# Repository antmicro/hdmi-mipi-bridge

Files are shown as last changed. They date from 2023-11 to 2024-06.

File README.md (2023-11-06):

# HDMI to MIPI CSI-2 Bridge

Copyright (c) 2017-2023 [Antmicro](https://www.antmicro.com)

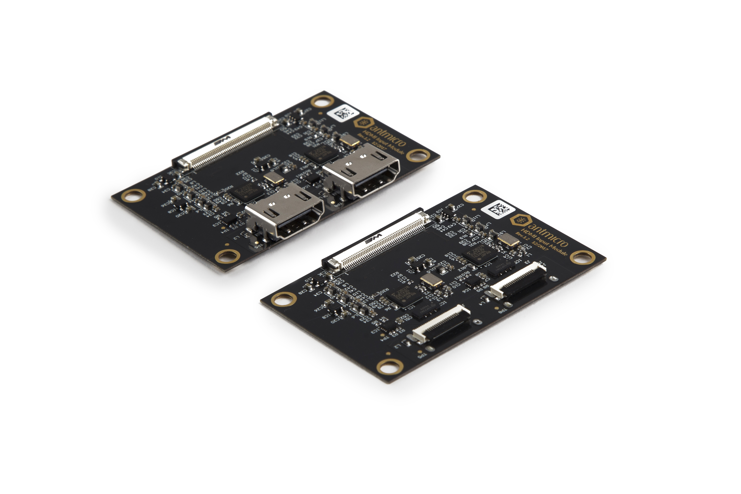
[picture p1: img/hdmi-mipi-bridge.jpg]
HDMI-MIPI Bridge


## Overview
This repository contains the open hardware design files for Antmicro's HDMI-MIPI Bridge, which is a video accessory converting HDMI video stream into MIPI CSI-2 counterpart.
The conversion is performed using Toshiba [TC358743XBG](https://toshiba.semicon-storage.com/ap-en/semiconductor/product/interface-bridge-ics-for-mobile-peripheral-devices/hdmir-interface-bridge-ics/detail.TC358743XBG.html) HDMI interface bridge.
The board includes two independent conversion channels supporting up to two HDMI streams.

## Repository structure:

The main repository directory contains KiCad PCB project files, a [LICENSE](LICENSE), and a README.
The remaining files are stored in the following directories:

* `lib` - contains component libraries
* `doc` - contains generated schematics and other documentation
* `img` - contains graphics for this README

## Key features

* Two independent HDMI-MIPI CSI-2 conversion channels
* Converted MIPI CSI-2 data is exposed on two 4-lane interfaces
* Two assembly variants for regular HDMI and FFC connectors

## Supported platforms

The board exposes MIPI CSI-2 data on a unified 50-pin FFC connector which is electrically compatible with a variety of processing platforms designed by Antmicro.
Those platforms include: 

* [Jetson Nano / Xavier NX Baseboard](https://github.com/antmicro/jetson-nano-baseboard)
* [Jetson Orin NX Baseboard](https://github.com/antmicro/jetson-orin-baseboard)
* [Google Coral Baseboard](https://github.com/antmicro/google-coral-baseboard)
* [Apalis Smart Vision Baseboard](https://github.com/antmicro/apalis-smart-vision-baseboard)
* [TX2 Deep Learning Platform](https://github.com/antmicro/jetson-tx2-deep-learning-platform)

Please note that some additional work might be required to integrate this board with a particular host platform.
Antmicro’s services involve BSP development so you can hire us to make the necessary modifications.

## License

This project is licensed under the [Apache-2.0](LICENSE) license.

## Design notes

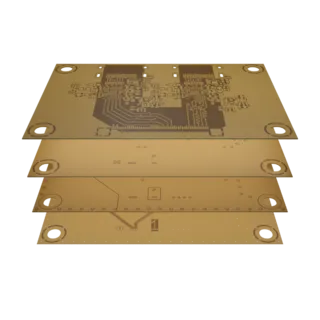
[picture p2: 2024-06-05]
assets/previews/layer1_thumbnail.webp

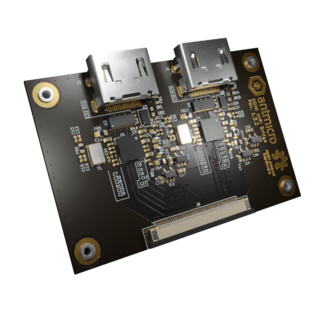
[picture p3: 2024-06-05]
assets/previews/leftT_thumbnail.png

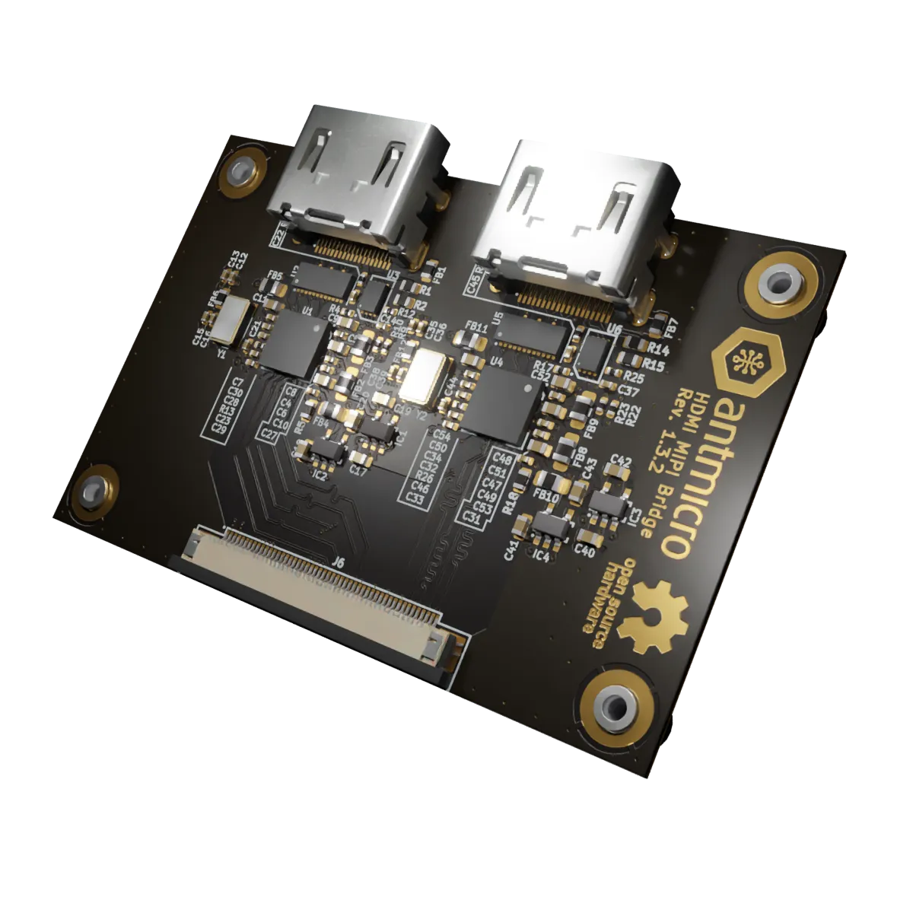
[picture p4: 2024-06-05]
assets/previews/rightT.webp

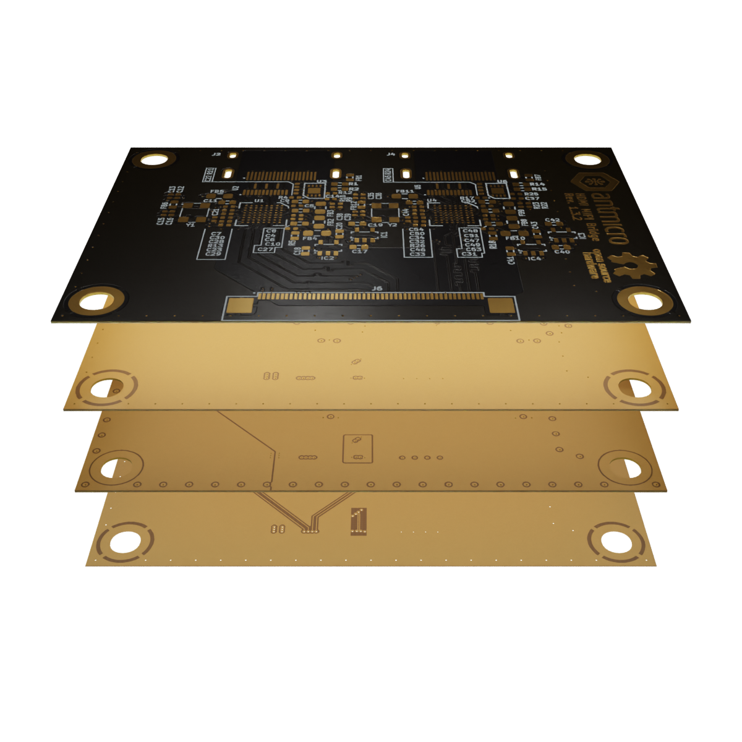
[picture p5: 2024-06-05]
assets/previews/stackup.png

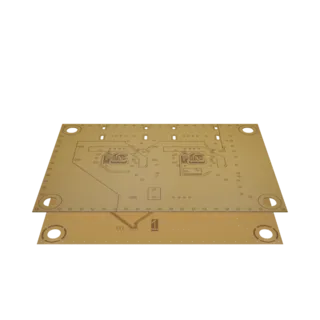
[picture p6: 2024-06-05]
assets/previews/layer3_thumbnail.webp

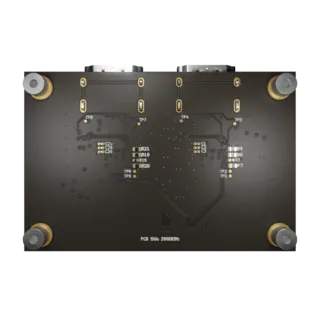
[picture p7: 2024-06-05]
assets/previews/orthoB_thumbnail.webp

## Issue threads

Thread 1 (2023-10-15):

unable obtain 3D

LaurentDelaon, 2023-10-15:
Hi
I am trying use your framework under kicad 6.0.
I can open project in edit schema
Under PCBEdit I am unable to obtain components and 3D step with kicad.

Seem it not found path of your project.

Thanks for help.
Laurent.

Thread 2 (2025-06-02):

Does anyone build these for purchasing?

john--, 2025-06-02:
Kudos to the authors for releasing this. But I know from my history that these FFC connectors are tricky to solder. I've melted so many of them! Any chance that anyone sells these pre-made boards?

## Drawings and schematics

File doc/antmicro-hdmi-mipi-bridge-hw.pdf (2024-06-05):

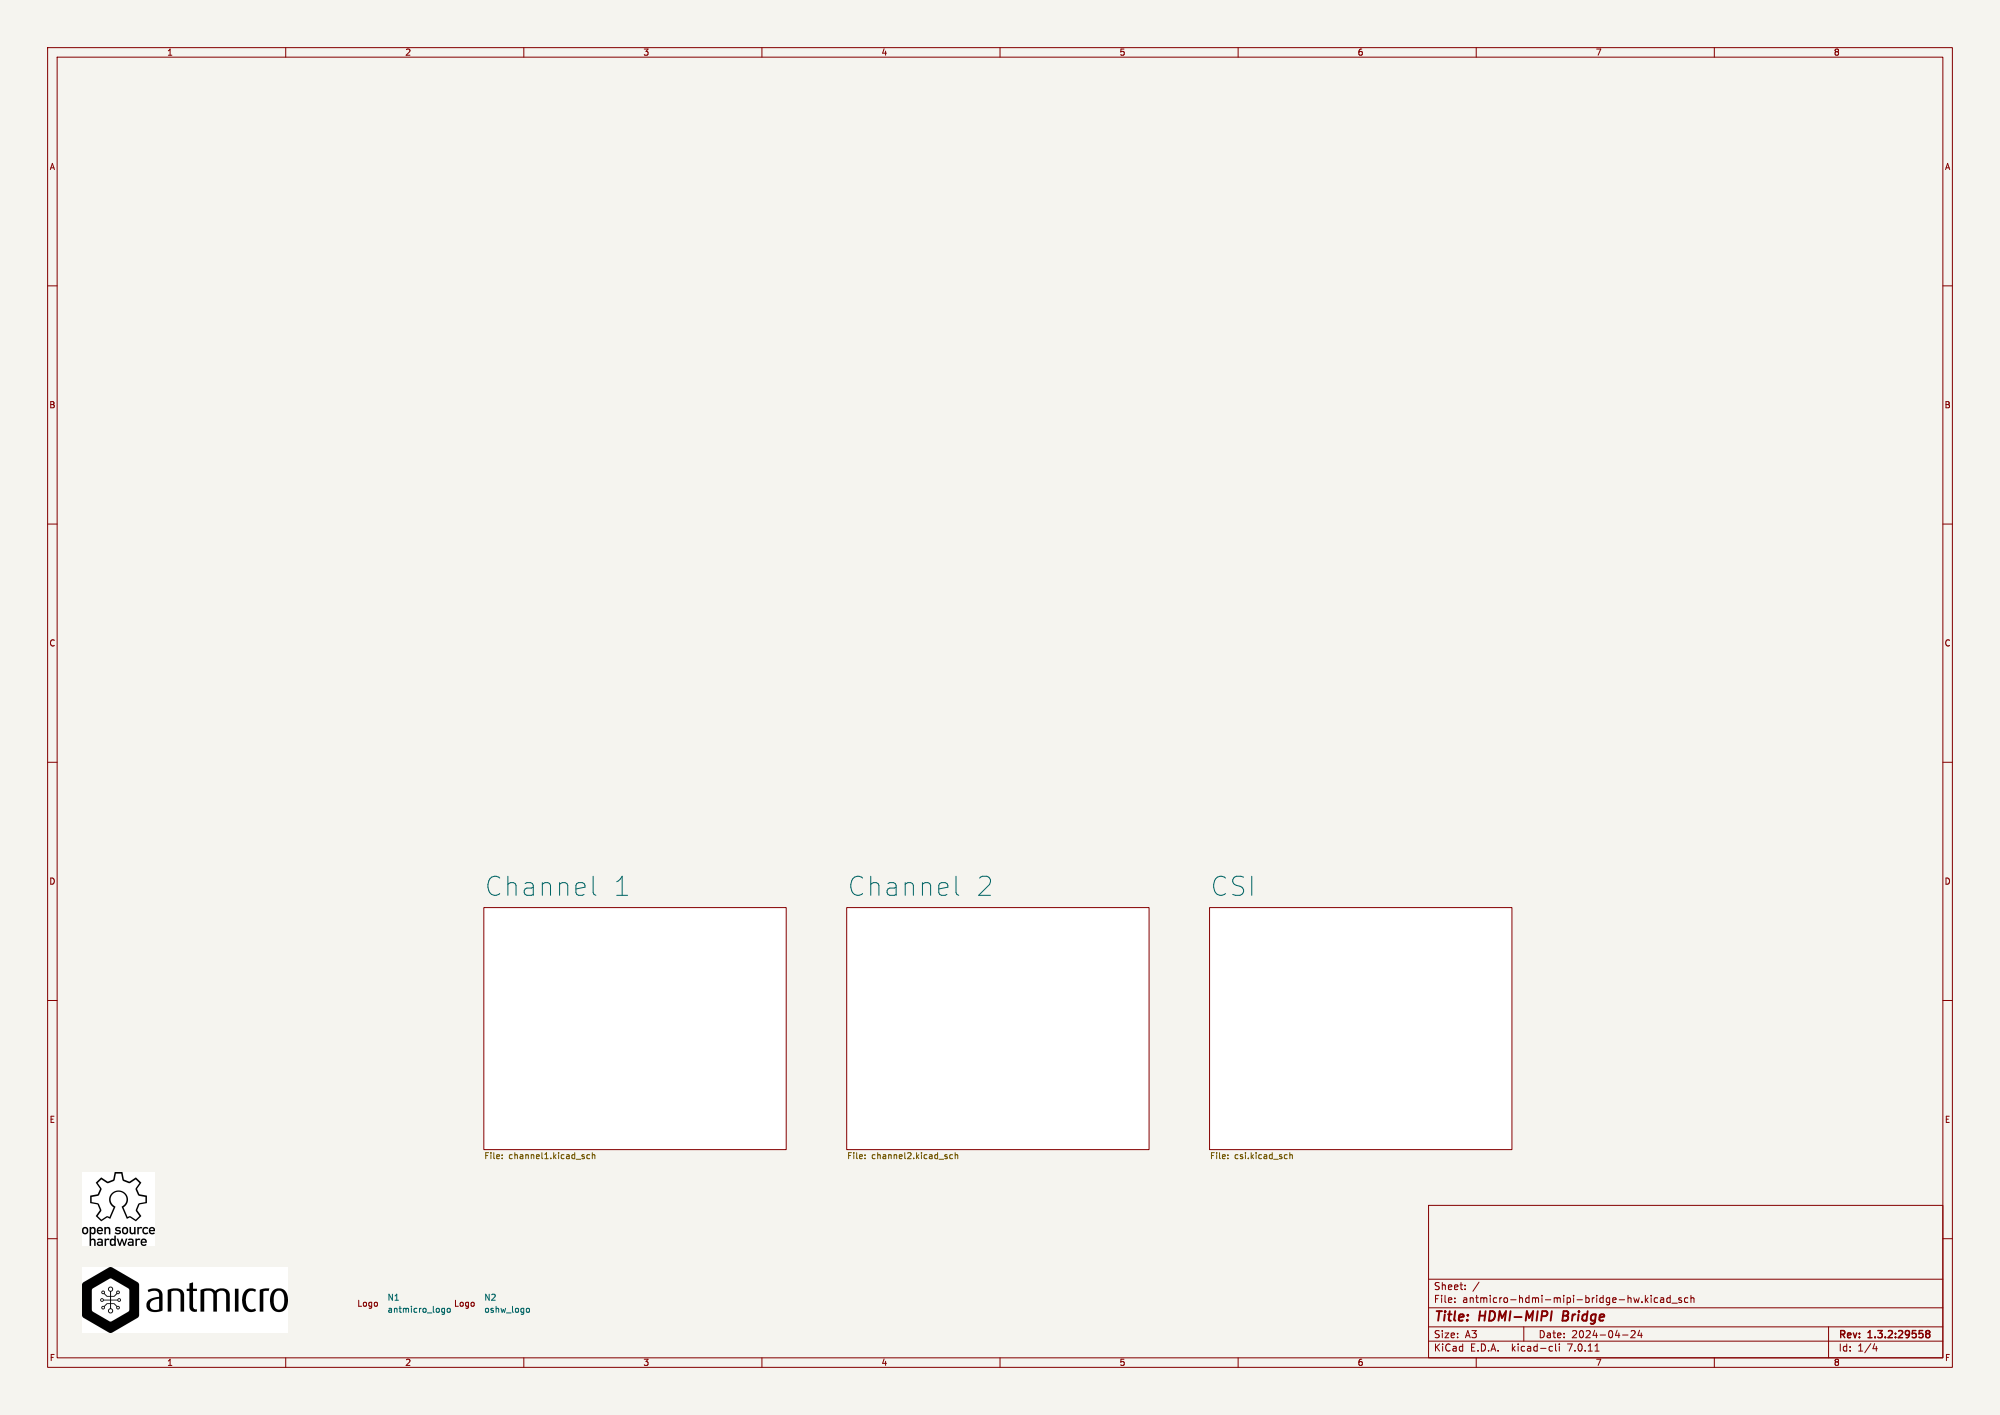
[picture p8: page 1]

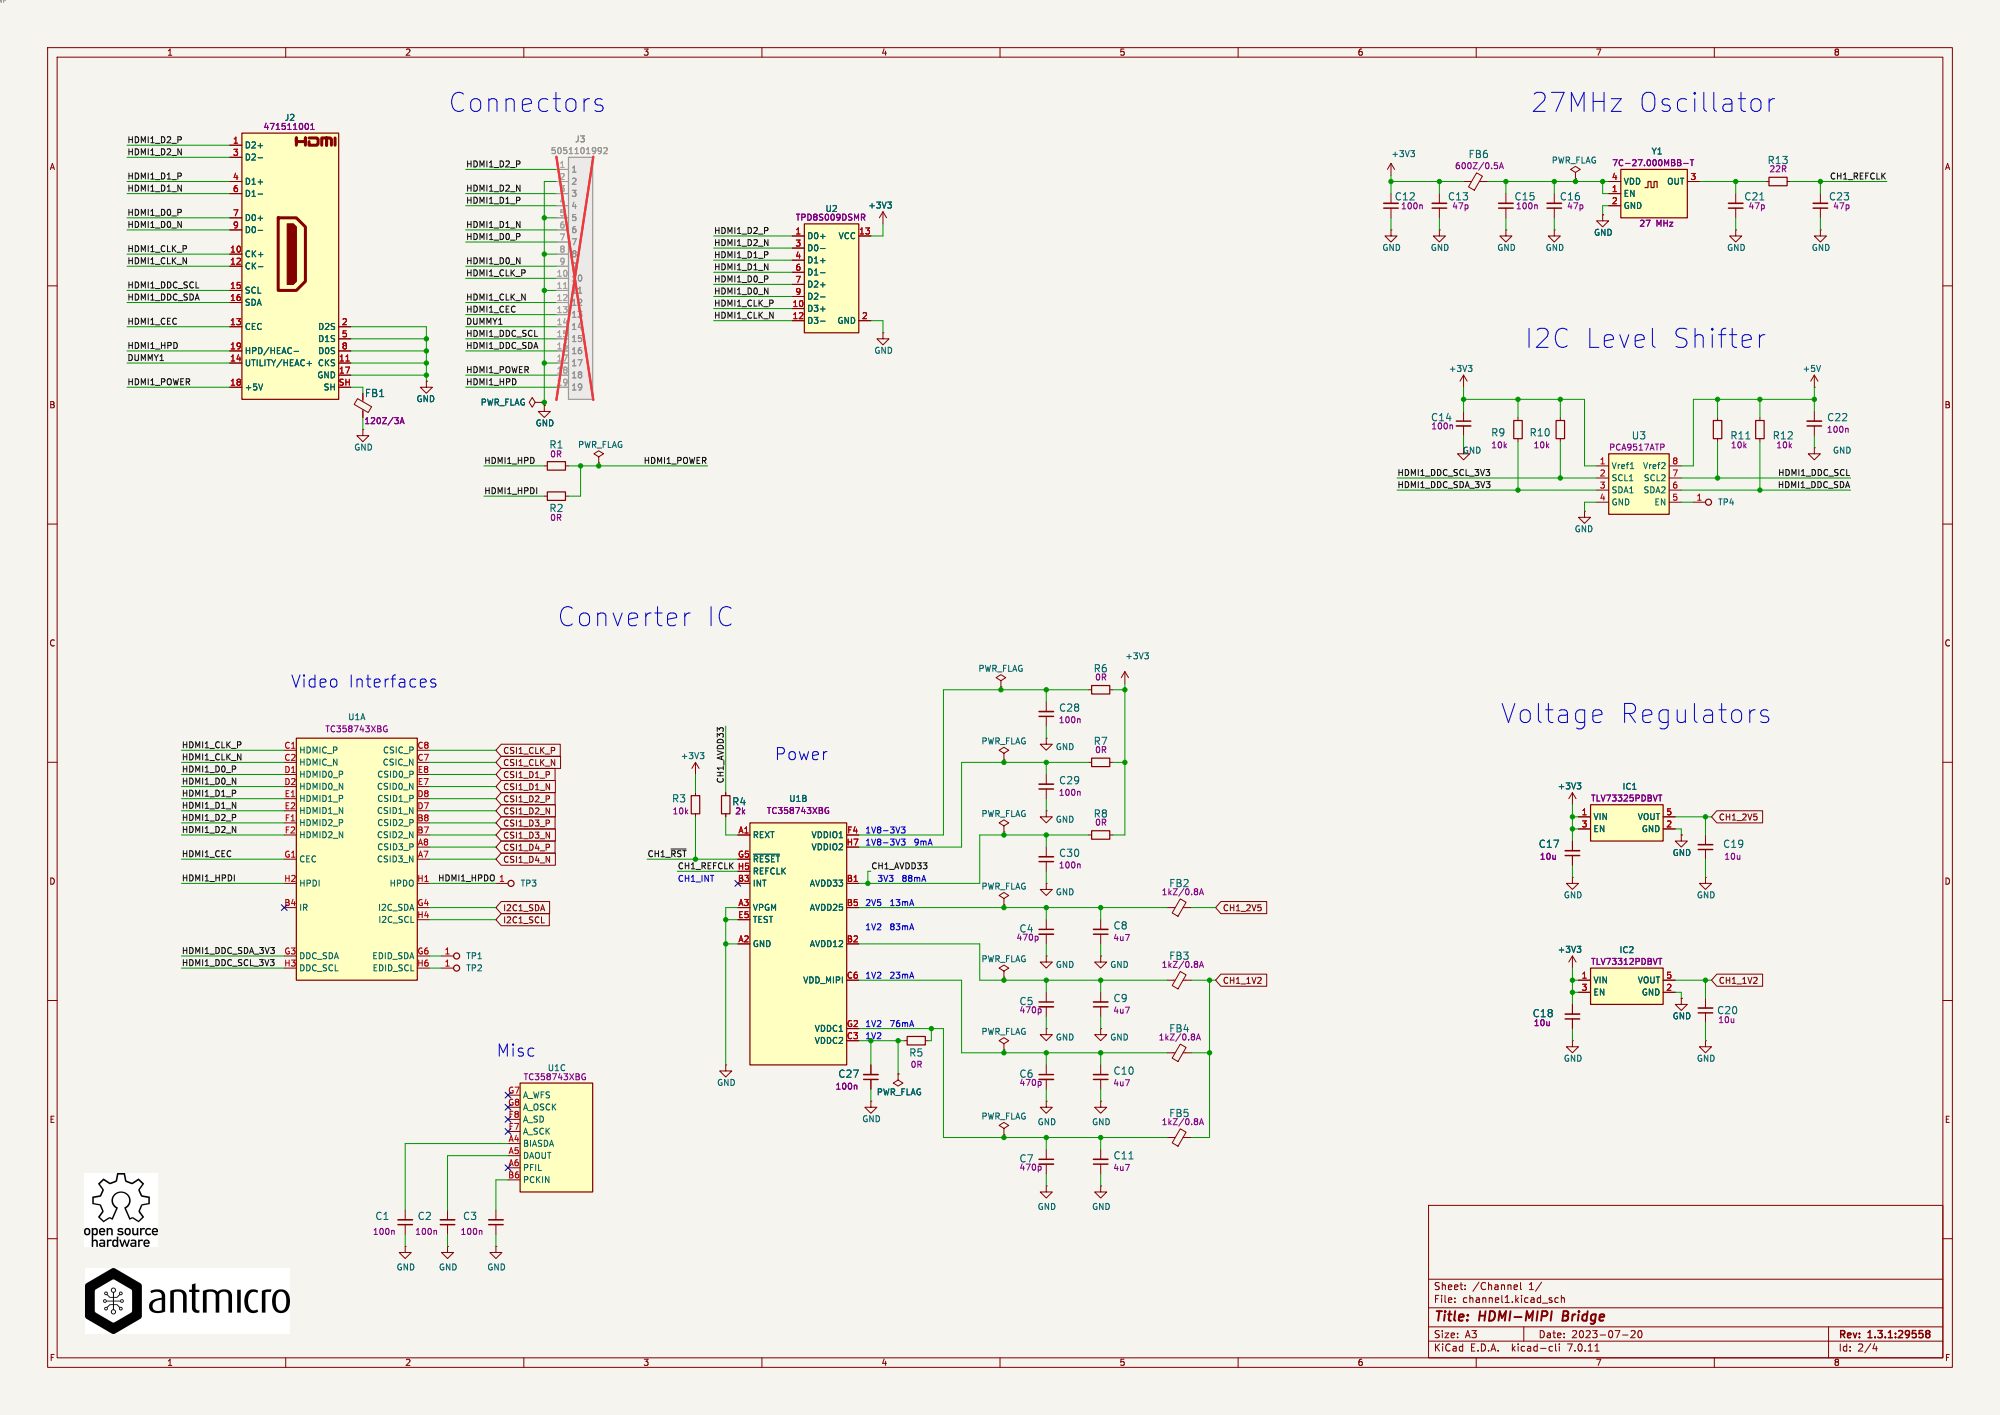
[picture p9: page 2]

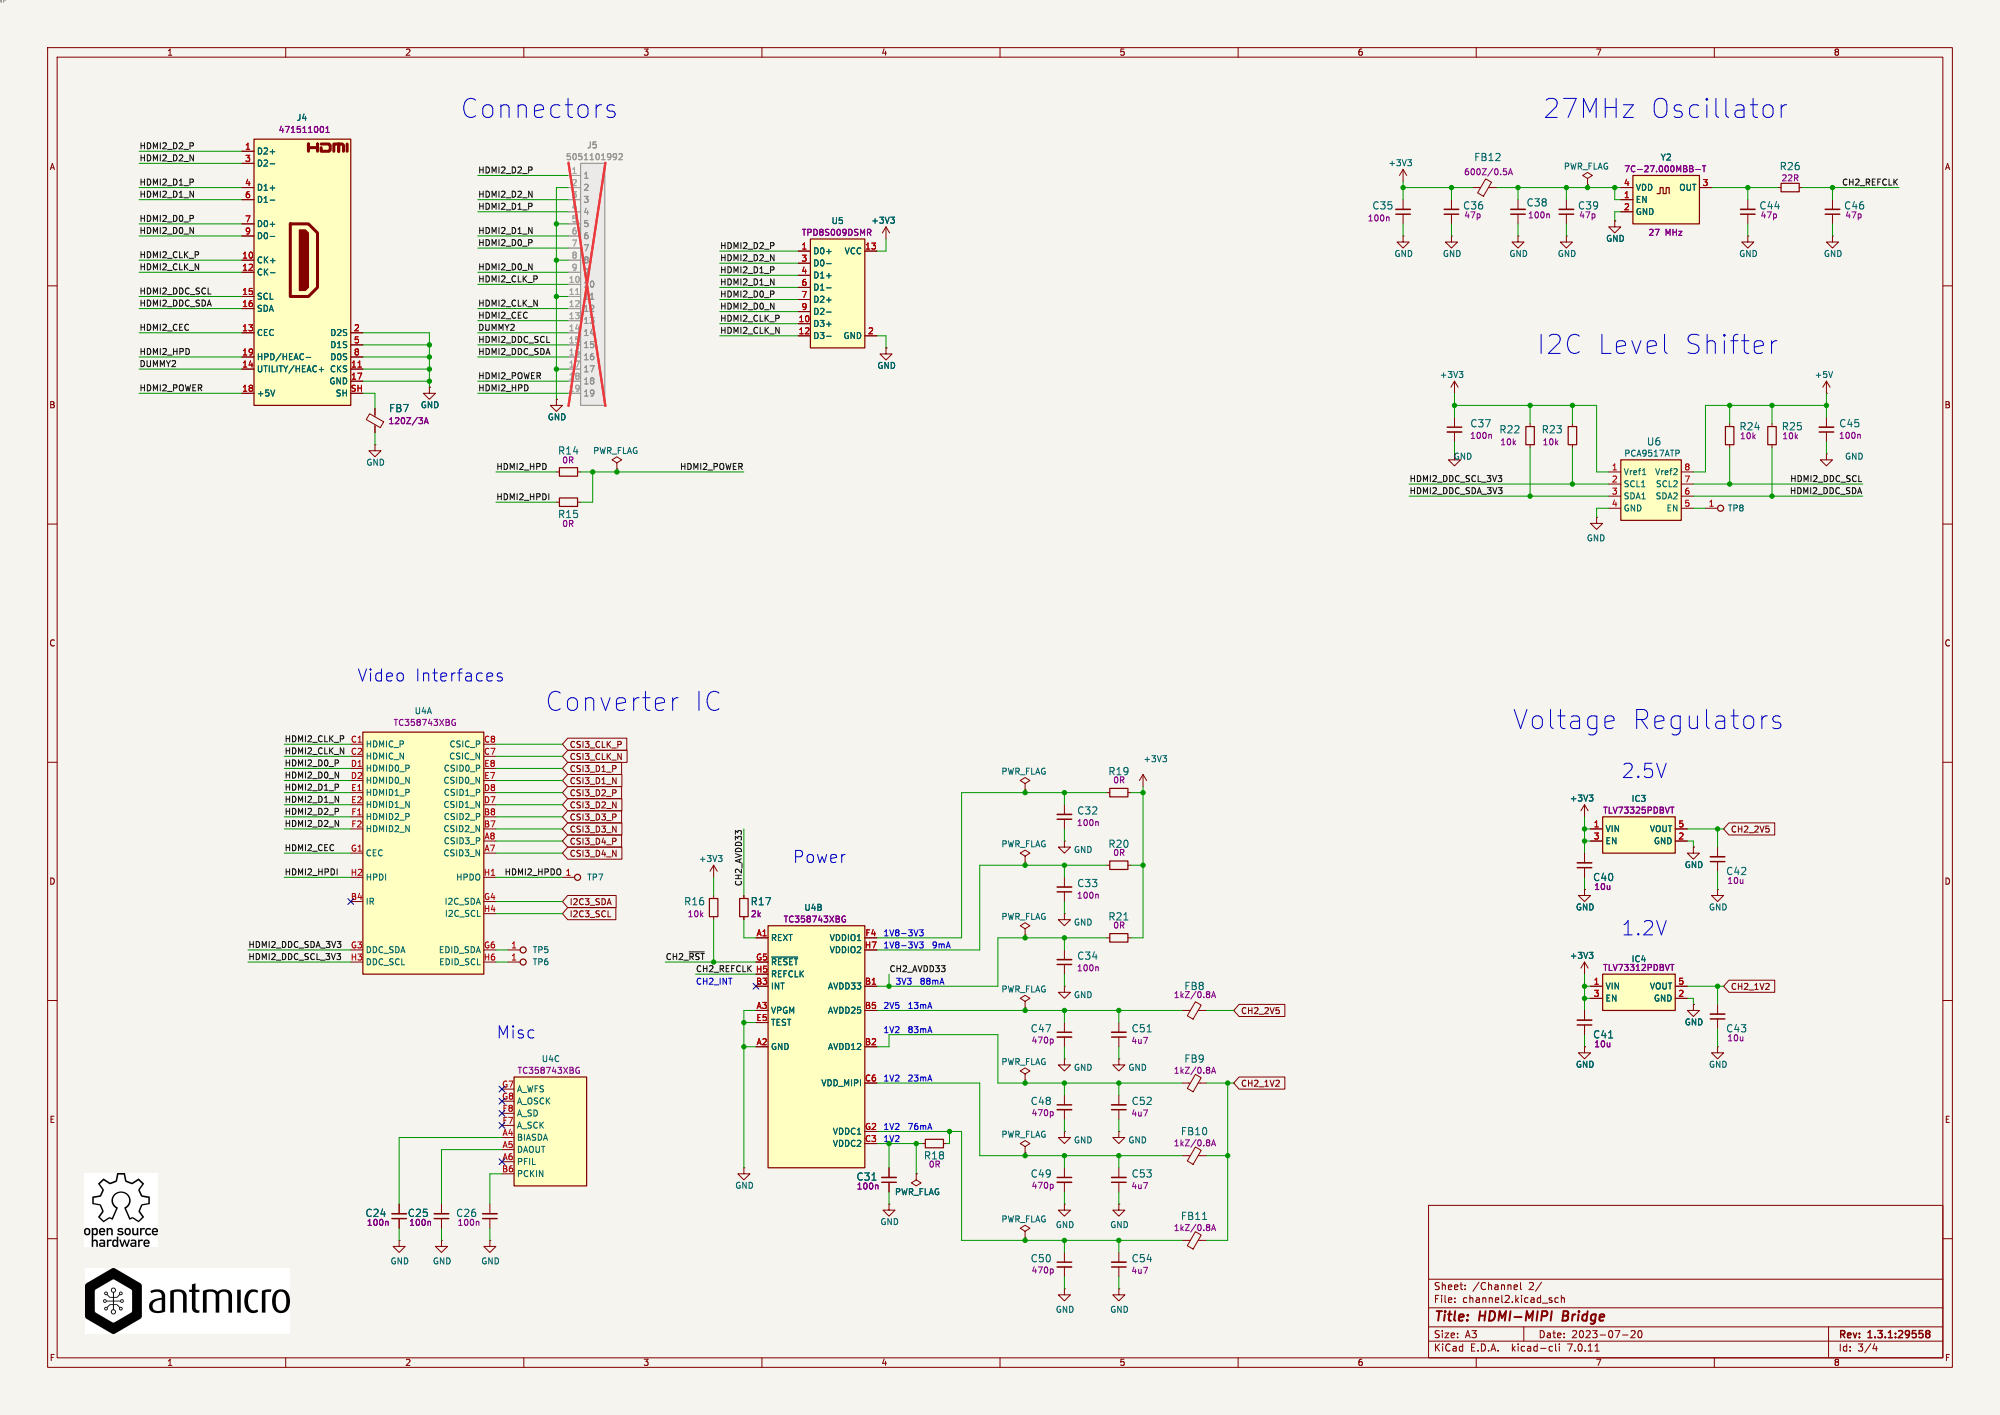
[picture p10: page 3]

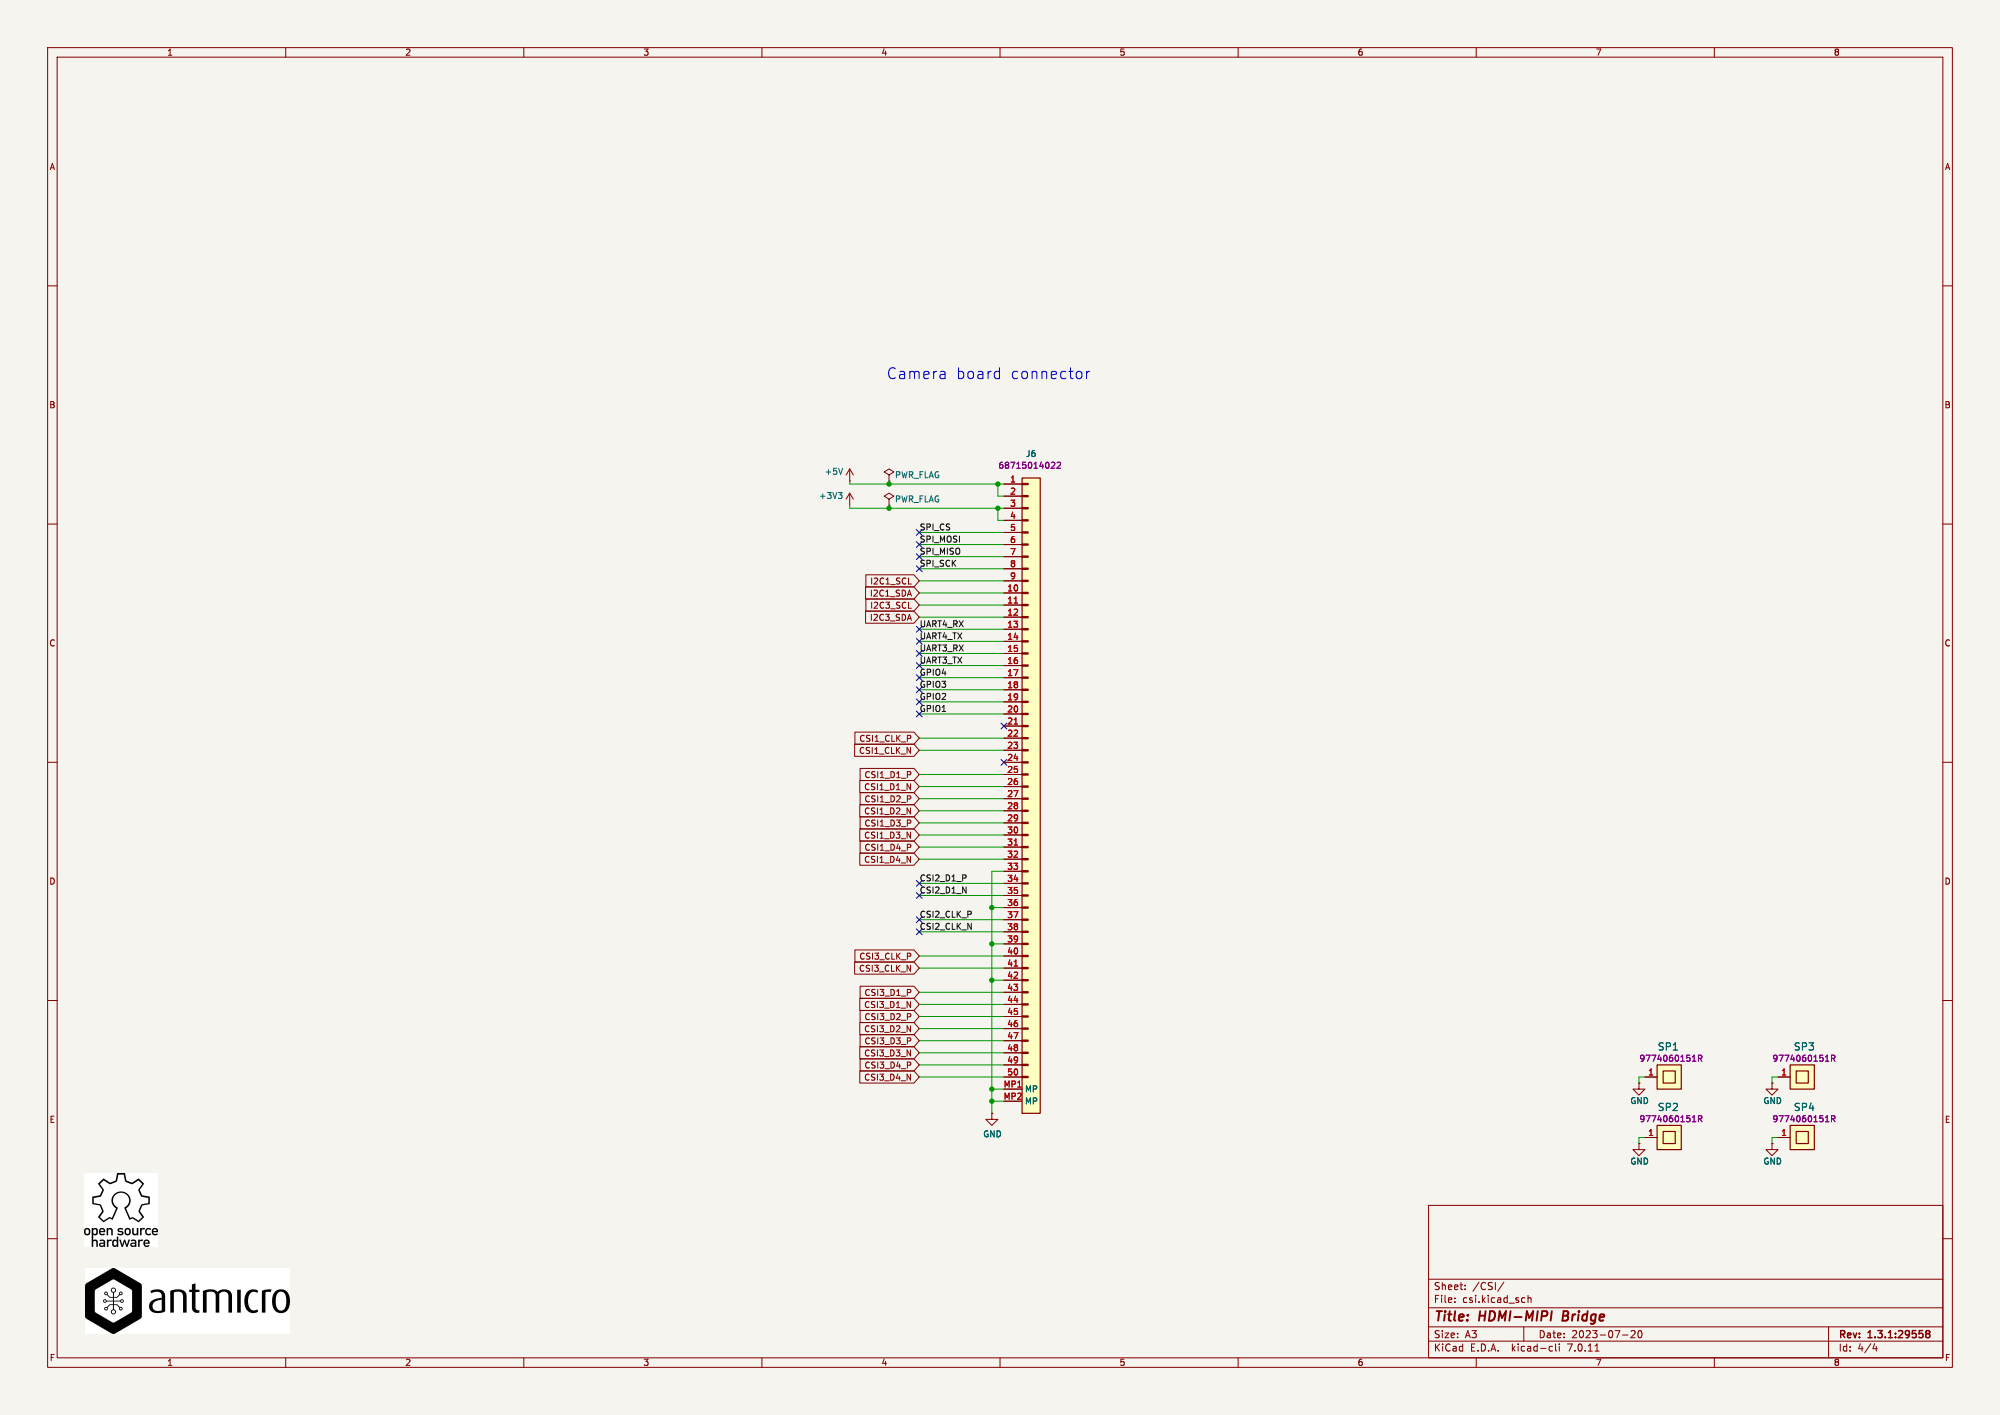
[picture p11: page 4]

File: csi.kicad_sch Sheet: /CSI/

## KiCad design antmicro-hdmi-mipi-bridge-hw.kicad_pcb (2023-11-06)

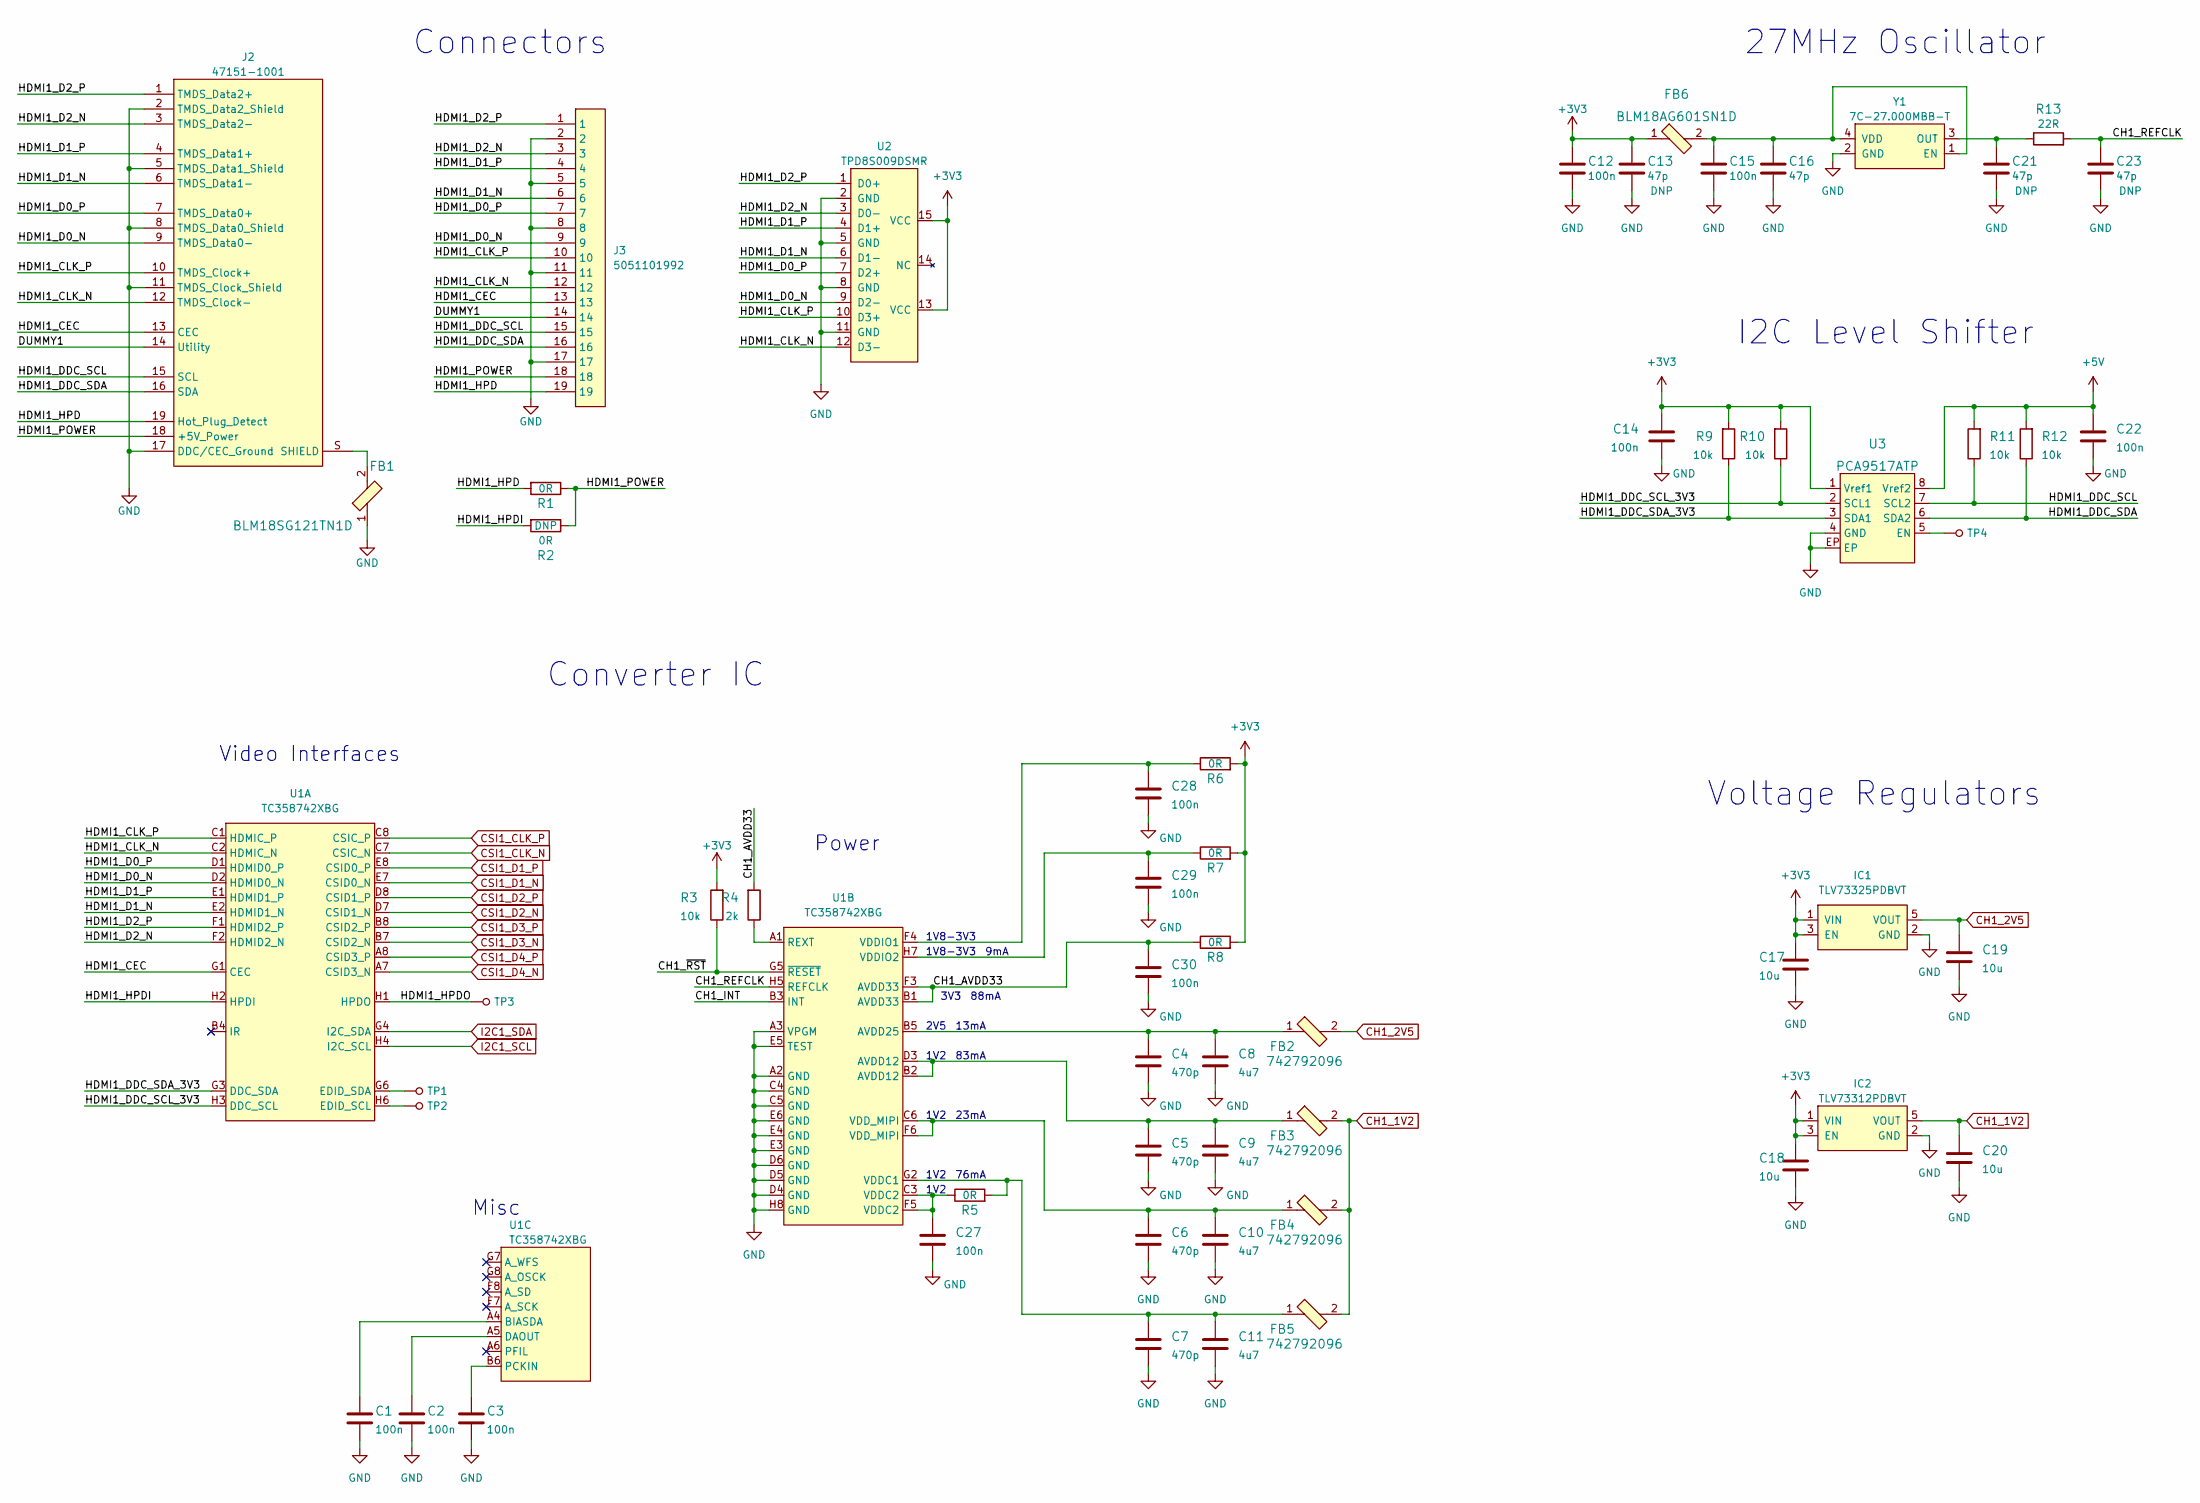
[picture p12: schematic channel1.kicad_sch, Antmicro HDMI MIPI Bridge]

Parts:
C1, C2, C3, C12, C14, C15, C22, C27, C28, C29, C30: C_100n_0402; 0402-cap; MPN GRM155R61H104KE14D
C4, C5, C6, C7: C_470p_0402; 0402-cap; MPN 0402B471K250CT
C8, C9, C10, C11: C_4u7_0603; 0603-cap; MPN C1608X5R1V475M080AC
C13, C16, C21, C23: C_47p_0402; 0402-cap; MPN C0402C470J5GACTU
C17, C18, C19, C20: C_10u_0603; 0603-cap; MPN GRM188R61A106KE69D
FB1: BLM18SG121TN1D; 0603-res; MPN BLM18SG121TN1D
FB2, FB3, FB4, FB5: 742792096; 0805-res; MPN 742792096
FB6: BLM18AG601SN1D; 0603; MPN BLM18AG601SN1D
IC1: TLV73325PDBVT; SOT-23-5; MPN TLV73325PDBVT
IC2: TLV73312PDBVT; SOT-23-5; MPN TLV73312PDBVT
J2: 47151-1001; MPN 47151-1001
J3: 5051101992; MPN 5051101992
R1, R2, R5, R6, R7, R8: R_0R_0603; 0603-res; MPN CR0603-J/-000ELF
R3, R9, R10, R11, R12: R_10k_0402; 0402-res; MPN CRCW040210K0FKEDHP
R4: R_2k_0402; 0402-res; MPN CRCW04022K00FKED
R13: R_22R_0402; 0402-res; MPN CRCW040222R0FKED
TP1, TP2, TP3, TP4: TP_SMD_0_75MM; Testpoint_smd_0_75mm
U1: TC358742XBG; BGA-64_8x8_6.0x6.0mm; MPN TC358742XBG
U2: TPD8S009DSMR; R-PDSO-N15; MPN TPD8S009DSMR
U3: PCA9517ATP; SOT1069-2; MPN PCA9517ATP
Y1: 7C-27.000MBB-T; 7C-24.000MBB-T; MPN 7C-27.000MBB-T

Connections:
+3V3: C12.1, C13.1, C14.1, C17.1, C18.1, FB6.1, IC1.1 (VIN), IC1.3 (EN), IC2.1 (VIN), IC2.3 (EN), R3.2, R6.2, R7.2, R8.2, R9.2, R10.2, U2.13 (VCC), U2.15 (VCC), U3.1 (Vref1); also elsewhere on the board
+5V: C22.1, R11.2, R12.2, U3.8 (Vref2); also elsewhere on the board
/Channel 1/CH1_AVDD33: C30.1, R4.2, R8.1, U1.B1 (AVDD33), U1.F3 (AVDD33)
/Channel 1/CH1_INT: U1.B3 (INT)
/Channel 1/CH1_REFCLK: C23.1, R13.2, U1.H5 (REFCLK)
/Channel 1/CH1_~RST: R3.1, U1.G5 (~RESET)
/Channel 1/DUMMY1: J2.14 (Utility), J3.14
/Channel 1/HDMI1_CEC: J2.13 (CEC), J3.13, U1.G1 (CEC)
/Channel 1/HDMI1_CLK_N: J2.12 (TMDS_Clock-), J3.12, U1.C2 (HDMIC_N), U2.12 (D3-)
/Channel 1/HDMI1_CLK_P: J2.10 (TMDS_Clock+), J3.10, U1.C1 (HDMIC_P), U2.10 (D3+)
/Channel 1/HDMI1_D0_N: J2.9 (TMDS_Data0-), J3.9, U1.D2 (HDMID0_N), U2.9 (D2-)
/Channel 1/HDMI1_D0_P: J2.7 (TMDS_Data0+), J3.7, U1.D1 (HDMID0_P), U2.7 (D2+)
/Channel 1/HDMI1_D1_N: J2.6 (TMDS_Data1-), J3.6, U1.E2 (HDMID1_N), U2.6 (D1-)
/Channel 1/HDMI1_D1_P: J2.4 (TMDS_Data1+), J3.4, U1.E1 (HDMID1_P), U2.4 (D1+)
/Channel 1/HDMI1_D2_N: J2.3 (TMDS_Data2-), J3.3, U1.F2 (HDMID2_N), U2.3 (D0-)
/Channel 1/HDMI1_D2_P: J2.1 (TMDS_Data2+), J3.1, U1.F1 (HDMID2_P), U2.1 (D0+)
/Channel 1/HDMI1_DDC_SCL: J2.15 (SCL), J3.15, R11.1, U3.7 (SCL2)
/Channel 1/HDMI1_DDC_SCL_3V3: R10.1, U1.H3 (DDC_SCL), U3.2 (SCL1)
/Channel 1/HDMI1_DDC_SDA: J2.16 (SDA), J3.16, R12.1, U3.6 (SDA2)
/Channel 1/HDMI1_DDC_SDA_3V3: R9.1, U1.G3 (DDC_SDA), U3.3 (SDA1)
/Channel 1/HDMI1_HPD: J2.19 (Hot_Plug_Detect), J3.19, R1.2
/Channel 1/HDMI1_HPDI: R2.2, U1.H2 (HPDI)
/Channel 1/HDMI1_HPDO: TP3.1, U1.H1 (HPDO)
/Channel 1/HDMI1_POWER: J2.18 (+5V_Power), J3.18, R1.1, R2.1
CH1_1V2: C20.1, FB3.2, FB4.2, FB5.2, IC2.5 (VOUT)
CH1_2V5: C19.1, FB2.2, IC1.5 (VOUT)
CSI1_CLK_N: U1.C7 (CSIC_N); also elsewhere on the board
CSI1_CLK_P: U1.C8 (CSIC_P); also elsewhere on the board
CSI1_D1_N: U1.E7 (CSID0_N); also elsewhere on the board
CSI1_D1_P: U1.E8 (CSID0_P); also elsewhere on the board
CSI1_D2_N: U1.D7 (CSID1_N); also elsewhere on the board
CSI1_D2_P: U1.D8 (CSID1_P); also elsewhere on the board
CSI1_D3_N: U1.B7 (CSID2_N); also elsewhere on the board
CSI1_D3_P: U1.B8 (CSID2_P); also elsewhere on the board
CSI1_D4_N: U1.A7 (CSID3_N); also elsewhere on the board
CSI1_D4_P: U1.A8 (CSID3_P); also elsewhere on the board
GND: C1.2, C2.2, C3.2, C4.1, C5.1, C6.1, C7.1, C8.2, C9.2, C10.2, C11.2, C12.2, C13.2, C14.2, C15.2, C16.2, C17.2, C18.2, C19.2, C20.2, C21.2, C22.2, C23.2, C27.2, C28.2, C29.2, C30.2, FB1.1, IC1.2 (GND), IC2.2 (GND), J2.2 (TMDS_Data2_Shield), J2.5 (TMDS_Data1_Shield), J2.8 (TMDS_Data0_Shield), J2.11 (TMDS_Clock_Shield), J2.17 (DDC/CEC_Ground), J3.2, J3.5, J3.8, J3.11, J3.17, U1.A2 (GND), U1.A3 (VPGM), U1.C4 (GND), U1.C5 (GND), U1.D4 (GND), U1.D5 (GND), U1.D6 (GND), U1.E3 (GND), U1.E4 (GND), U1.E5 (TEST), U1.E6 (GND), U1.H8 (GND), U2.2 (GND), U2.5 (GND), U2.8 (GND), U2.11 (GND), U3.4 (GND), U3.EP, Y1.2 (GND); also elsewhere on the board
I2C1_SCL: U1.H4 (I2C_SCL); also elsewhere on the board
I2C1_SDA: U1.G4 (I2C_SDA); also elsewhere on the board
unnamed: C1.1, U1.A4 (BIASDA)
unnamed: C2.1, U1.A5 (DAOUT)
unnamed: C3.1, U1.B6 (PCKIN)
unnamed: C4.2, C8.1, FB2.1, U1.B5 (AVDD25)
unnamed: C5.2, C9.1, FB3.1, U1.B2 (AVDD12), U1.D3 (AVDD12)
unnamed: C6.2, C10.1, FB4.1, U1.C6 (VDD_MIPI), U1.F6 (VDD_MIPI)
unnamed: C7.2, C11.1, FB5.1, R5.2, U1.G2 (VDDC1)
unnamed: C15.1, C16.1, FB6.2, Y1.1 (EN), Y1.4 (VDD)
unnamed: C21.1, R13.1, Y1.3 (OUT)
unnamed: C27.1, R5.1, U1.C3 (VDDC2), U1.F5 (VDDC2)
unnamed: C28.1, R6.1, U1.F4 (VDDIO1)
unnamed: C29.1, R7.1, U1.H7 (VDDIO2)
unnamed: FB1.2, J2.S (SHIELD)
unnamed: R4.1, U1.A1 (REXT)
unnamed: TP1.1, U1.G6 (EDID_SDA)
unnamed: TP2.1, U1.H6 (EDID_SCL)
unnamed: TP4.1, U3.5 (EN)

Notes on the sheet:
Video Interfaces
88mA
Converter IC
1V2
76mA
1V8-3V3
I2C Level Shifter
9mA
2V5
Connectors
13mA
Voltage Regulators
3V3
27MHz Oscillator
Power
23mA
Misc
83mA

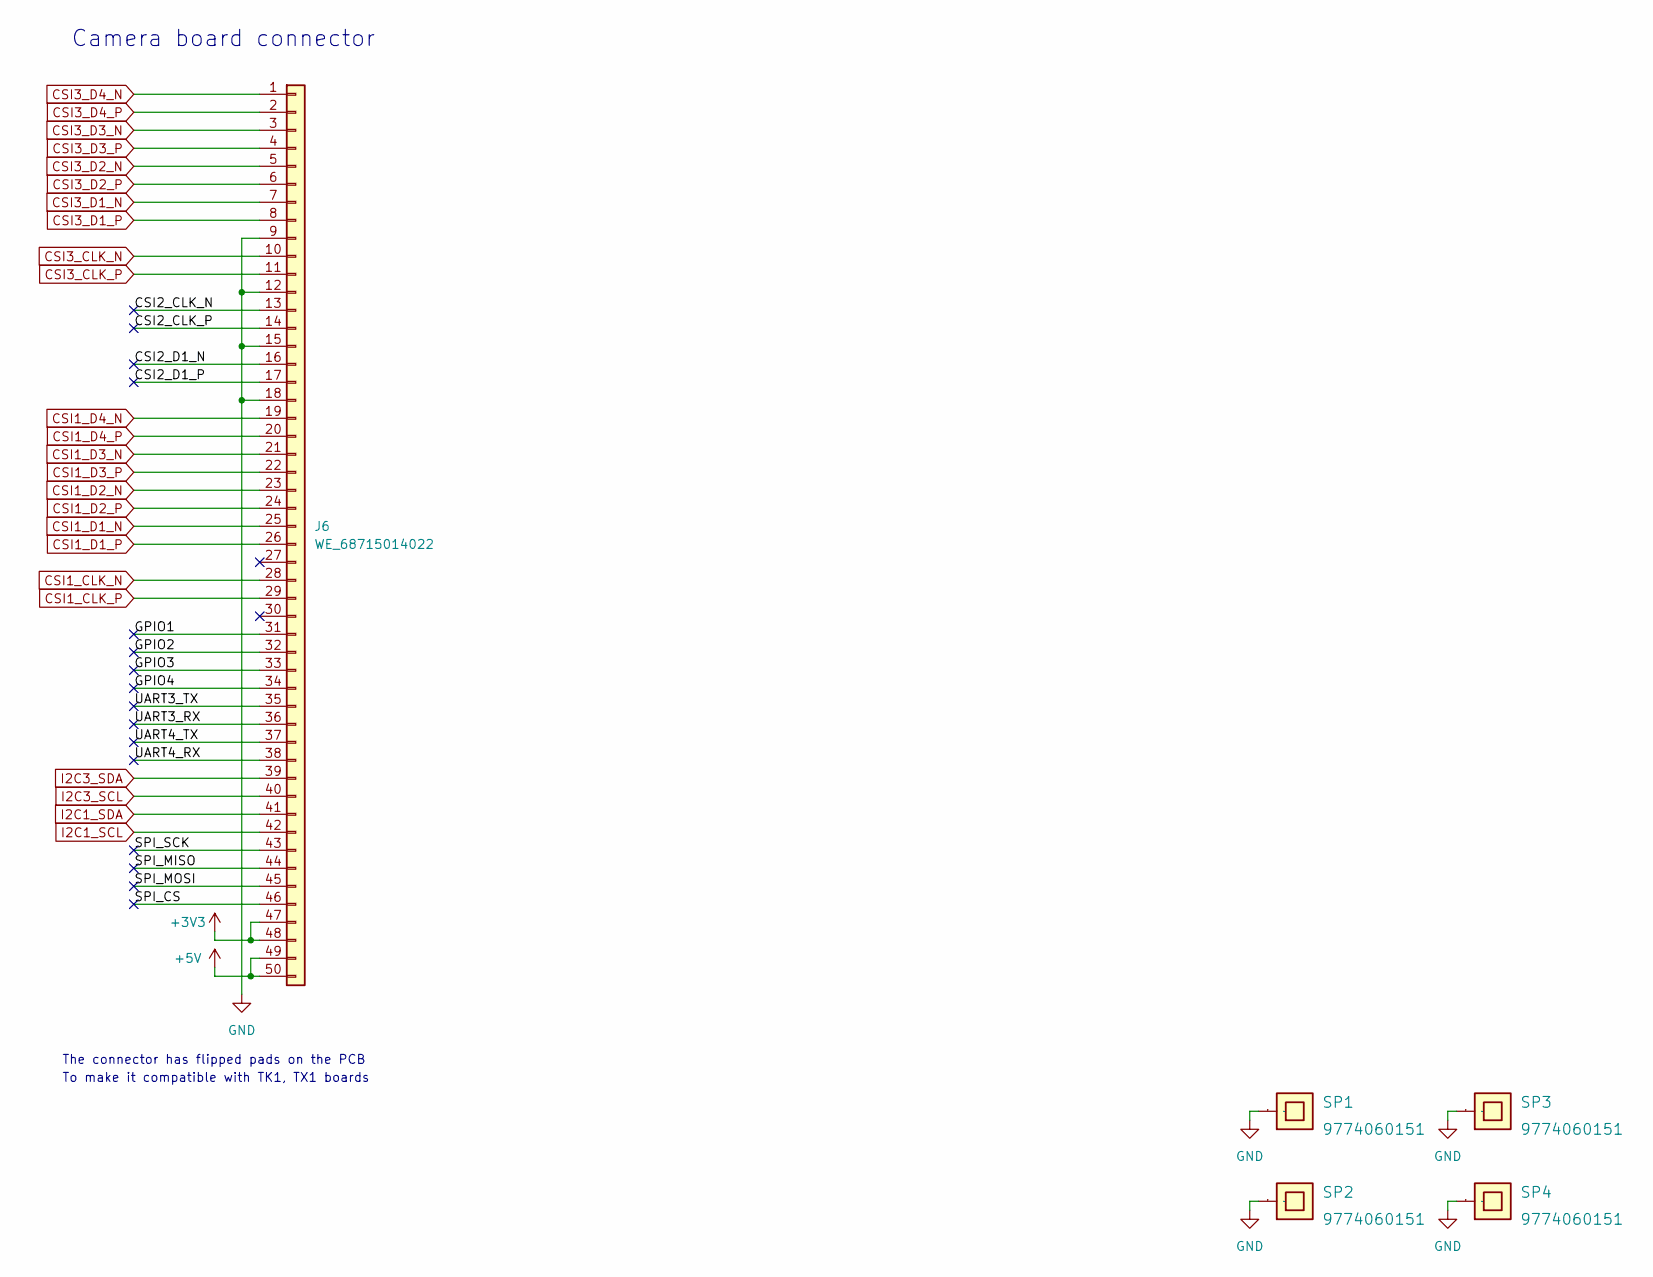
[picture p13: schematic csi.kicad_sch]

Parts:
J6: WE_68715014022; MPN 68715014022
SP1, SP2, SP3, SP4: 9774060151; MPN 9774060151

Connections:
+3V3: J6.47, J6.48; also elsewhere on the board
+5V: J6.49, J6.50; also elsewhere on the board
/CSI/CSI2_CLK_N: J6.13
/CSI/CSI2_CLK_P: J6.14
/CSI/CSI2_D1_N: J6.16
/CSI/CSI2_D1_P: J6.17
/CSI/GPIO1: J6.31
/CSI/GPIO2: J6.32
/CSI/GPIO3: J6.33
/CSI/GPIO4: J6.34
/CSI/SPI_CS: J6.46
/CSI/SPI_MISO: J6.44
/CSI/SPI_MOSI: J6.45
/CSI/SPI_SCK: J6.43
/CSI/UART3_RX: J6.36
/CSI/UART3_TX: J6.35
/CSI/UART4_RX: J6.38
/CSI/UART4_TX: J6.37
CSI1_CLK_N: J6.28; also elsewhere on the board
CSI1_CLK_P: J6.29; also elsewhere on the board
CSI1_D1_N: J6.25; also elsewhere on the board
CSI1_D1_P: J6.26; also elsewhere on the board
CSI1_D2_N: J6.23; also elsewhere on the board
CSI1_D2_P: J6.24; also elsewhere on the board
CSI1_D3_N: J6.21; also elsewhere on the board
CSI1_D3_P: J6.22; also elsewhere on the board
CSI1_D4_N: J6.19; also elsewhere on the board
CSI1_D4_P: J6.20; also elsewhere on the board
CSI3_CLK_N: J6.10; also elsewhere on the board
CSI3_CLK_P: J6.11; also elsewhere on the board
CSI3_D1_N: J6.7; also elsewhere on the board
CSI3_D1_P: J6.8; also elsewhere on the board
CSI3_D2_N: J6.5; also elsewhere on the board
CSI3_D2_P: J6.6; also elsewhere on the board
CSI3_D3_N: J6.3; also elsewhere on the board
CSI3_D3_P: J6.4; also elsewhere on the board
CSI3_D4_N: J6.1; also elsewhere on the board
CSI3_D4_P: J6.2; also elsewhere on the board
GND: J6.9, J6.12, J6.15, J6.18, SP1.1, SP2.1, SP3.1, SP4.1; also elsewhere on the board
I2C1_SCL: J6.42; also elsewhere on the board
I2C1_SDA: J6.41; also elsewhere on the board
I2C3_SCL: J6.40; also elsewhere on the board
I2C3_SDA: J6.39; also elsewhere on the board

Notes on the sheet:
To make it compatible with TK1, TX1 boards
Camera board connector
The connector has flipped pads on the PCB

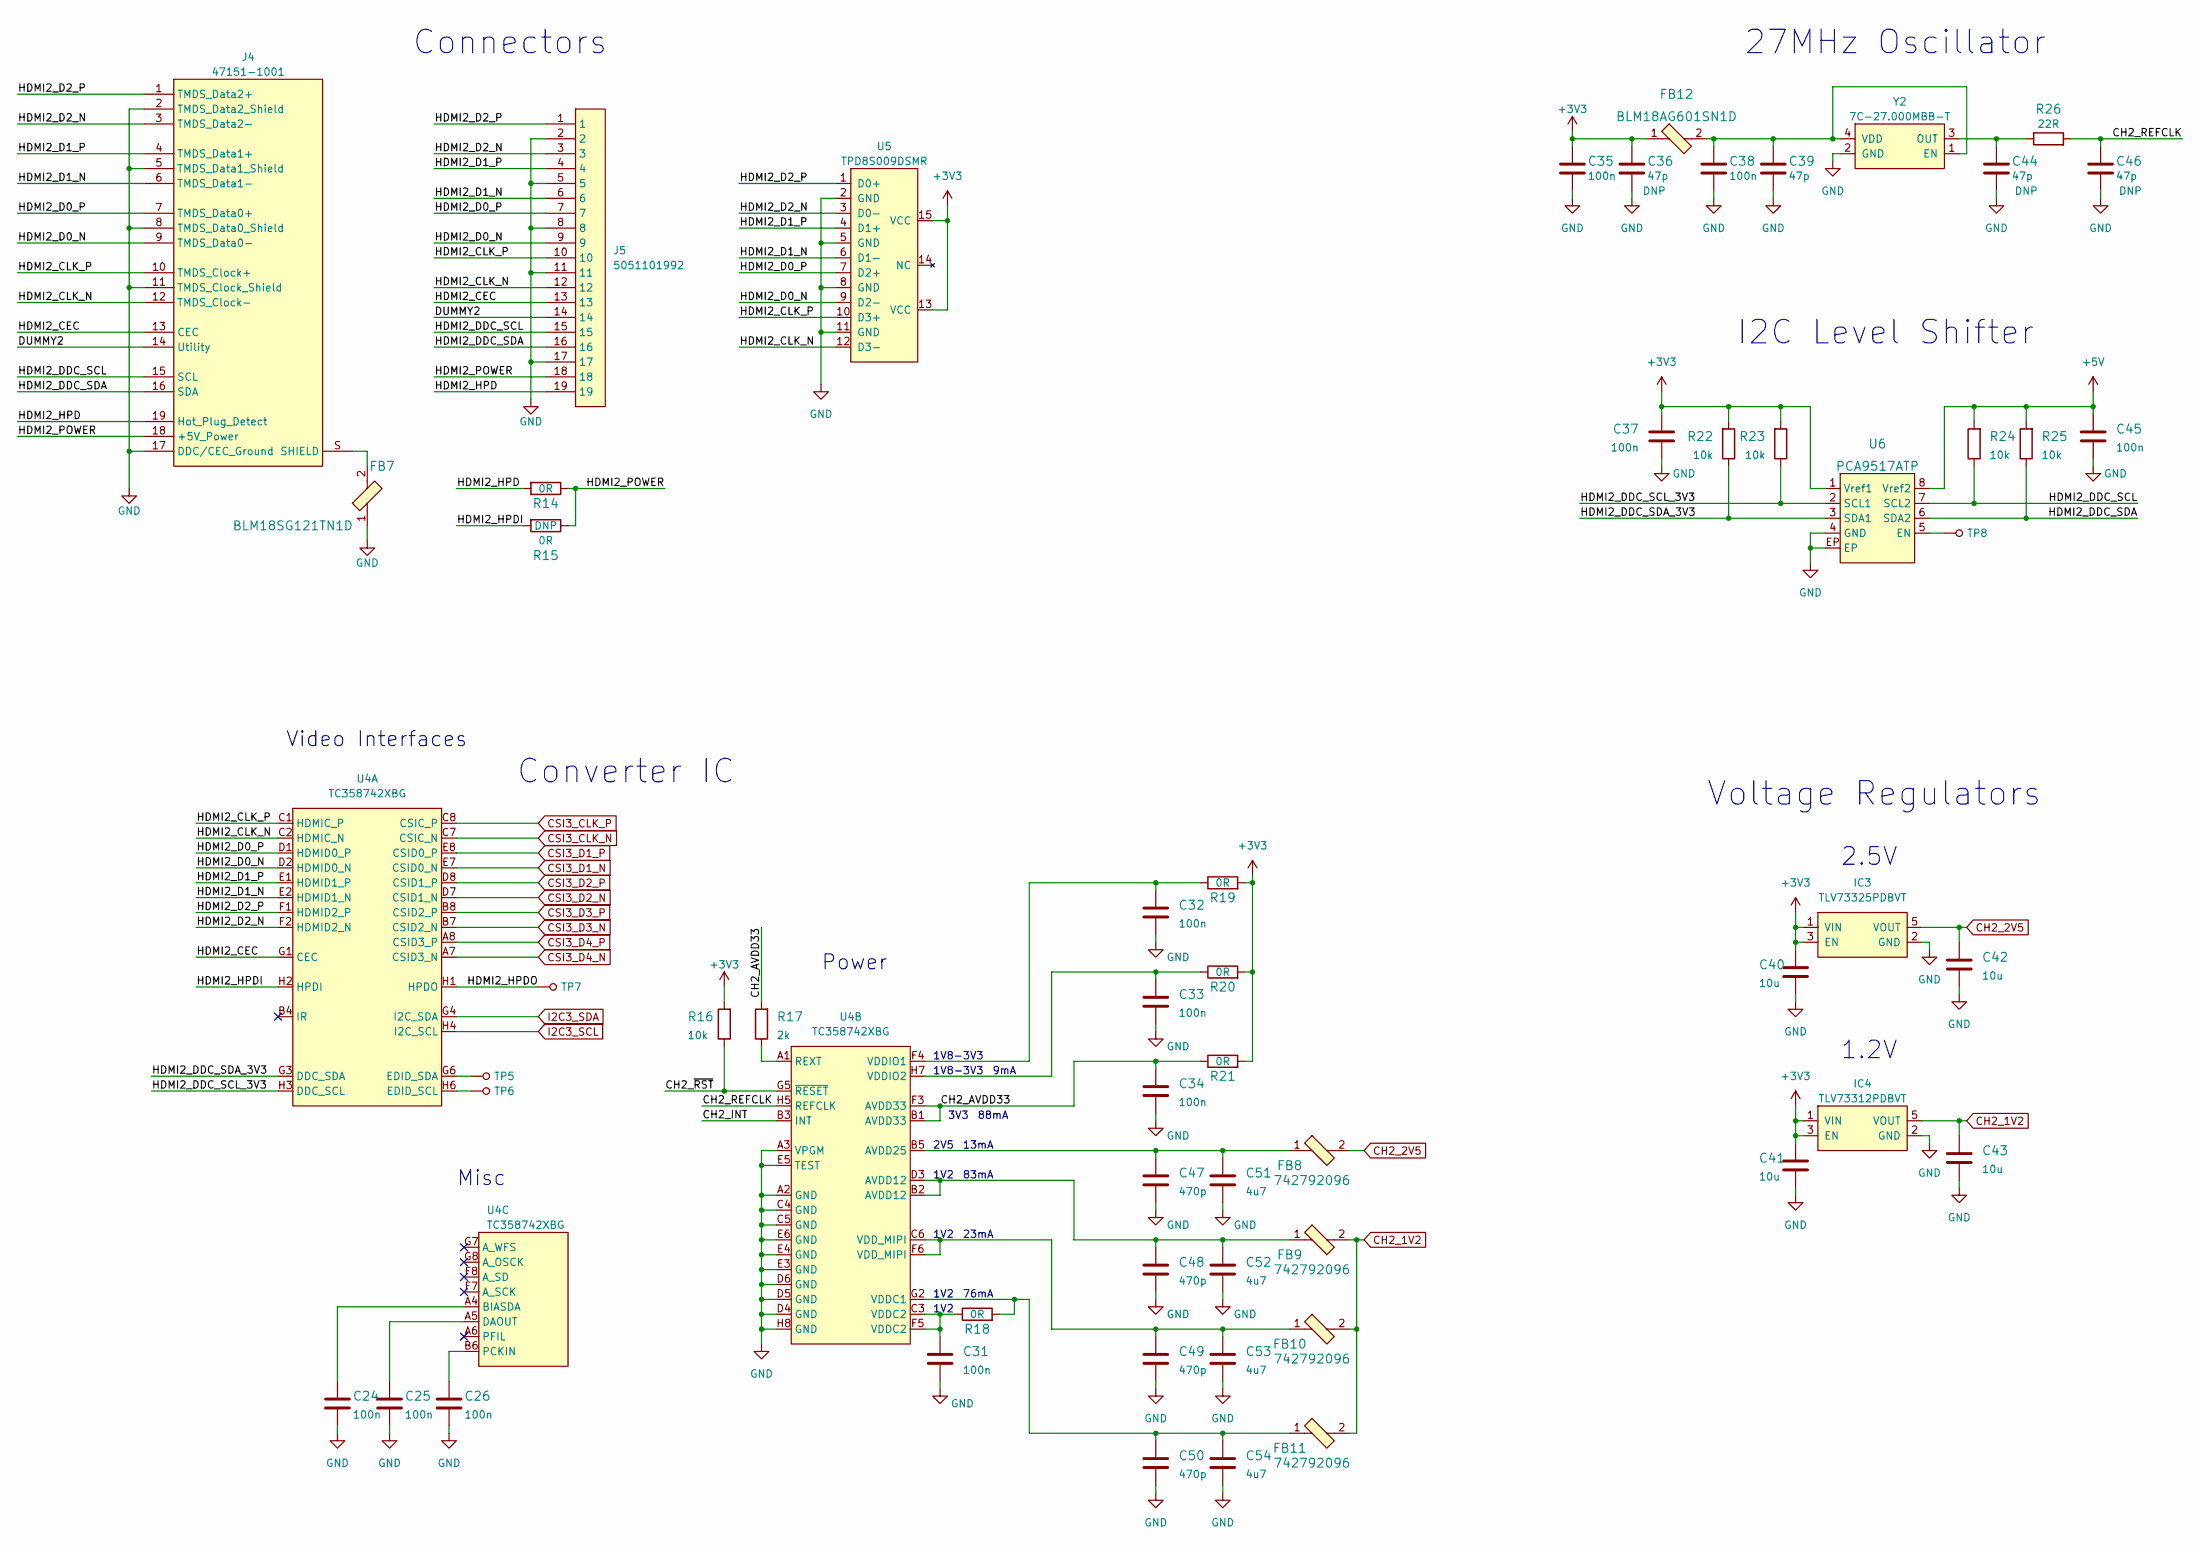
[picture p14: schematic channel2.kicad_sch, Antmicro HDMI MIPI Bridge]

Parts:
C24, C25, C26, C31, C32, C33, C34, C35, C37, C38, C45: C_100n_0402; 0402-cap; MPN GRM155R61H104KE14D
C36, C39, C44, C46: C_47p_0402; 0402-cap; MPN C0402C470J5GACTU
C40, C41, C42, C43: C_10u_0603; 0603-cap; MPN GRM188R61A106KE69D
C47, C48, C49, C50: C_470p_0402; 0402-cap; MPN 0402B471K250CT
C51, C52, C53, C54: C_4u7_0603; 0603-cap; MPN C1608X5R1V475M080AC
FB7: BLM18SG121TN1D; 0603-res; MPN BLM18SG121TN1D
FB8, FB9, FB10, FB11: 742792096; 0805-res; MPN 742792096
FB12: BLM18AG601SN1D; 0603; MPN BLM18AG601SN1D
IC3: TLV73325PDBVT; SOT-23-5; MPN TLV73325PDBVT
IC4: TLV73312PDBVT; SOT-23-5; MPN TLV73312PDBVT
J4: 47151-1001; MPN 47151-1001
J5: 5051101992; MPN 5051101992
R14, R15, R18, R19, R20, R21: R_0R_0603; 0603-res; MPN CR0603-J/-000ELF
R16, R22, R23, R24, R25: R_10k_0402; 0402-res; MPN CRCW040210K0FKEDHP
R17: R_2k_0402; 0402-res; MPN CRCW04022K00FKED
R26: R_22R_0402; 0402-res; MPN CRCW040222R0FKED
TP5, TP6, TP7, TP8: TP_SMD_0_75MM; Testpoint_smd_0_75mm
U4: TC358742XBG; BGA-64_8x8_6.0x6.0mm; MPN TC358742XBG
U5: TPD8S009DSMR; R-PDSO-N15; MPN TPD8S009DSMR
U6: PCA9517ATP; SOT1069-2; MPN PCA9517ATP
Y2: 7C-27.000MBB-T; 7C-24.000MBB-T; MPN 7C-27.000MBB-T

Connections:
+3V3: C35.1, C36.1, C37.1, C40.1, C41.1, FB12.1, IC3.1 (VIN), IC3.3 (EN), IC4.1 (VIN), IC4.3 (EN), R16.2, R19.2, R20.2, R21.2, R22.2, R23.2, U5.13 (VCC), U5.15 (VCC), U6.1 (Vref1); also elsewhere on the board
+5V: C45.1, R24.2, R25.2, U6.8 (Vref2); also elsewhere on the board
/Channel 2/CH2_AVDD33: C34.1, R17.2, R21.1, U4.B1 (AVDD33), U4.F3 (AVDD33)
/Channel 2/CH2_INT: U4.B3 (INT)
/Channel 2/CH2_REFCLK: C46.1, R26.2, U4.H5 (REFCLK)
/Channel 2/CH2_~RST: R16.1, U4.G5 (~RESET)
/Channel 2/DUMMY2: J4.14 (Utility), J5.14
/Channel 2/HDMI2_CEC: J4.13 (CEC), J5.13, U4.G1 (CEC)
/Channel 2/HDMI2_CLK_N: J4.12 (TMDS_Clock-), J5.12, U4.C2 (HDMIC_N), U5.12 (D3-)
/Channel 2/HDMI2_CLK_P: J4.10 (TMDS_Clock+), J5.10, U4.C1 (HDMIC_P), U5.10 (D3+)
/Channel 2/HDMI2_D0_N: J4.9 (TMDS_Data0-), J5.9, U4.D2 (HDMID0_N), U5.9 (D2-)
/Channel 2/HDMI2_D0_P: J4.7 (TMDS_Data0+), J5.7, U4.D1 (HDMID0_P), U5.7 (D2+)
/Channel 2/HDMI2_D1_N: J4.6 (TMDS_Data1-), J5.6, U4.E2 (HDMID1_N), U5.6 (D1-)
/Channel 2/HDMI2_D1_P: J4.4 (TMDS_Data1+), J5.4, U4.E1 (HDMID1_P), U5.4 (D1+)
/Channel 2/HDMI2_D2_N: J4.3 (TMDS_Data2-), J5.3, U4.F2 (HDMID2_N), U5.3 (D0-)
/Channel 2/HDMI2_D2_P: J4.1 (TMDS_Data2+), J5.1, U4.F1 (HDMID2_P), U5.1 (D0+)
/Channel 2/HDMI2_DDC_SCL: J4.15 (SCL), J5.15, R24.1, U6.7 (SCL2)
/Channel 2/HDMI2_DDC_SCL_3V3: R23.1, U4.H3 (DDC_SCL), U6.2 (SCL1)
/Channel 2/HDMI2_DDC_SDA: J4.16 (SDA), J5.16, R25.1, U6.6 (SDA2)
/Channel 2/HDMI2_DDC_SDA_3V3: R22.1, U4.G3 (DDC_SDA), U6.3 (SDA1)
/Channel 2/HDMI2_HPD: J4.19 (Hot_Plug_Detect), J5.19, R14.2
/Channel 2/HDMI2_HPDI: R15.2, U4.H2 (HPDI)
/Channel 2/HDMI2_HPDO: TP7.1, U4.H1 (HPDO)
/Channel 2/HDMI2_POWER: J4.18 (+5V_Power), J5.18, R14.1, R15.1
CH2_1V2: C43.1, FB9.2, FB10.2, FB11.2, IC4.5 (VOUT)
CH2_2V5: C42.1, FB8.2, IC3.5 (VOUT)
CSI3_CLK_N: U4.C7 (CSIC_N); also elsewhere on the board
CSI3_CLK_P: U4.C8 (CSIC_P); also elsewhere on the board
CSI3_D1_N: U4.E7 (CSID0_N); also elsewhere on the board
CSI3_D1_P: U4.E8 (CSID0_P); also elsewhere on the board
CSI3_D2_N: U4.D7 (CSID1_N); also elsewhere on the board
CSI3_D2_P: U4.D8 (CSID1_P); also elsewhere on the board
CSI3_D3_N: U4.B7 (CSID2_N); also elsewhere on the board
CSI3_D3_P: U4.B8 (CSID2_P); also elsewhere on the board
CSI3_D4_N: U4.A7 (CSID3_N); also elsewhere on the board
CSI3_D4_P: U4.A8 (CSID3_P); also elsewhere on the board
GND: C24.2, C25.2, C26.2, C31.2, C32.2, C33.2, C34.2, C35.2, C36.2, C37.2, C38.2, C39.2, C40.2, C41.2, C42.2, C43.2, C44.2, C45.2, C46.2, C47.1, C48.1, C49.1, C50.1, C51.2, C52.2, C53.2, C54.2, FB7.1, IC3.2 (GND), IC4.2 (GND), J4.2 (TMDS_Data2_Shield), J4.5 (TMDS_Data1_Shield), J4.8 (TMDS_Data0_Shield), J4.11 (TMDS_Clock_Shield), J4.17 (DDC/CEC_Ground), J5.2, J5.5, J5.8, J5.11, J5.17, U4.A2 (GND), U4.A3 (VPGM), U4.C4 (GND), U4.C5 (GND), U4.D4 (GND), U4.D5 (GND), U4.D6 (GND), U4.E3 (GND), U4.E4 (GND), U4.E5 (TEST), U4.E6 (GND), U4.H8 (GND), U5.2 (GND), U5.5 (GND), U5.8 (GND), U5.11 (GND), U6.4 (GND), U6.EP, Y2.2 (GND); also elsewhere on the board
I2C3_SCL: U4.H4 (I2C_SCL); also elsewhere on the board
I2C3_SDA: U4.G4 (I2C_SDA); also elsewhere on the board
unnamed: C24.1, U4.A4 (BIASDA)
unnamed: C25.1, U4.A5 (DAOUT)
unnamed: C26.1, U4.B6 (PCKIN)
unnamed: C31.1, R18.1, U4.C3 (VDDC2), U4.F5 (VDDC2)
unnamed: C32.1, R19.1, U4.F4 (VDDIO1)
unnamed: C33.1, R20.1, U4.H7 (VDDIO2)
unnamed: C38.1, C39.1, FB12.2, Y2.1 (EN), Y2.4 (VDD)
unnamed: C44.1, R26.1, Y2.3 (OUT)
unnamed: C47.2, C51.1, FB8.1, U4.B5 (AVDD25)
unnamed: C48.2, C52.1, FB9.1, U4.B2 (AVDD12), U4.D3 (AVDD12)
unnamed: C49.2, C53.1, FB10.1, U4.C6 (VDD_MIPI), U4.F6 (VDD_MIPI)
unnamed: C50.2, C54.1, FB11.1, R18.2, U4.G2 (VDDC1)
unnamed: FB7.2, J4.S (SHIELD)
unnamed: R17.1, U4.A1 (REXT)
unnamed: TP5.1, U4.G6 (EDID_SDA)
unnamed: TP6.1, U4.H6 (EDID_SCL)
unnamed: TP8.1, U6.5 (EN)

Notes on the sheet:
1V2
1V8-3V3
9mA
3V3
83mA
Video Interfaces
1.2V
13mA
27MHz Oscillator
23mA
76mA
Connectors
2V5
2.5V
Converter IC
Power
Voltage Regulators
Misc
I2C Level Shifter
88mA

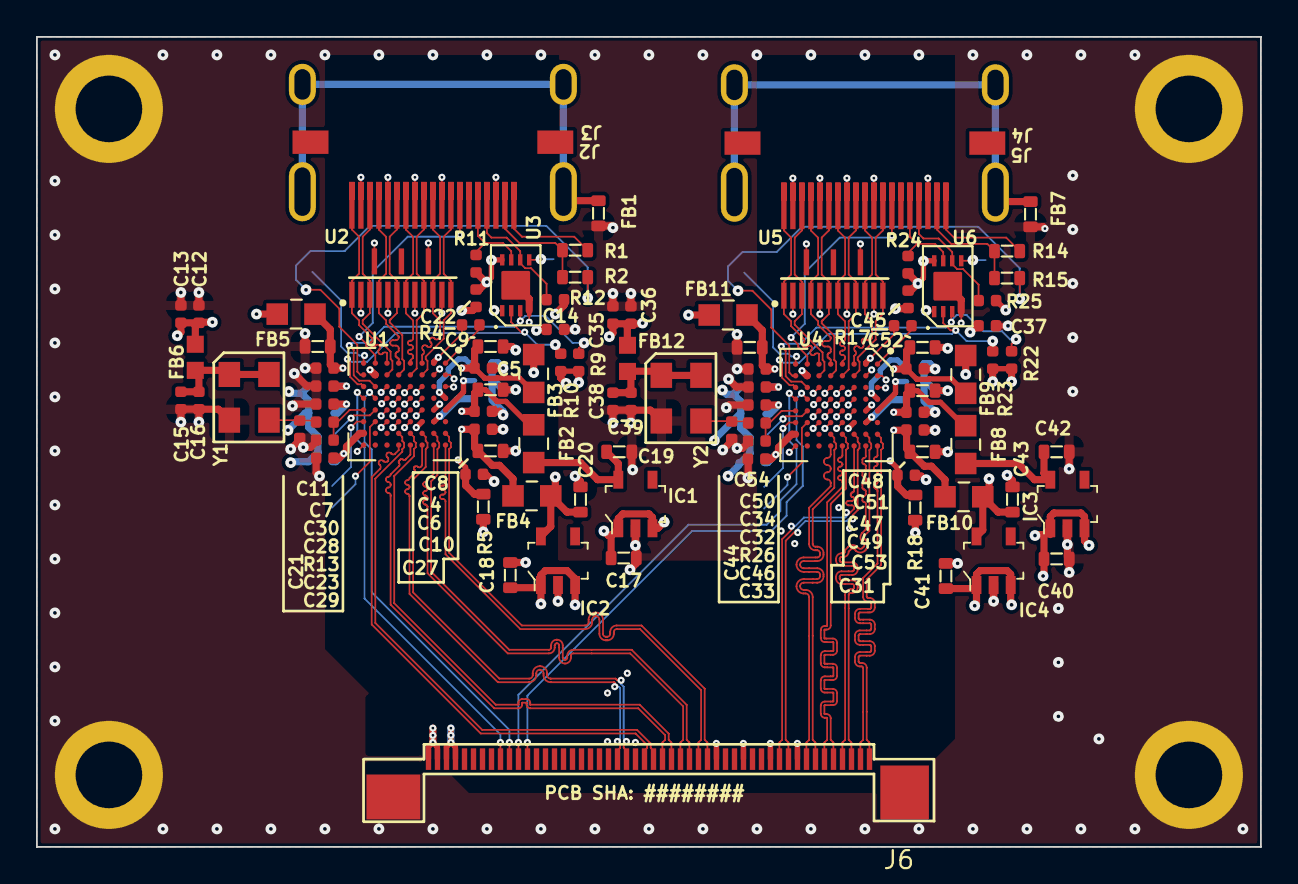
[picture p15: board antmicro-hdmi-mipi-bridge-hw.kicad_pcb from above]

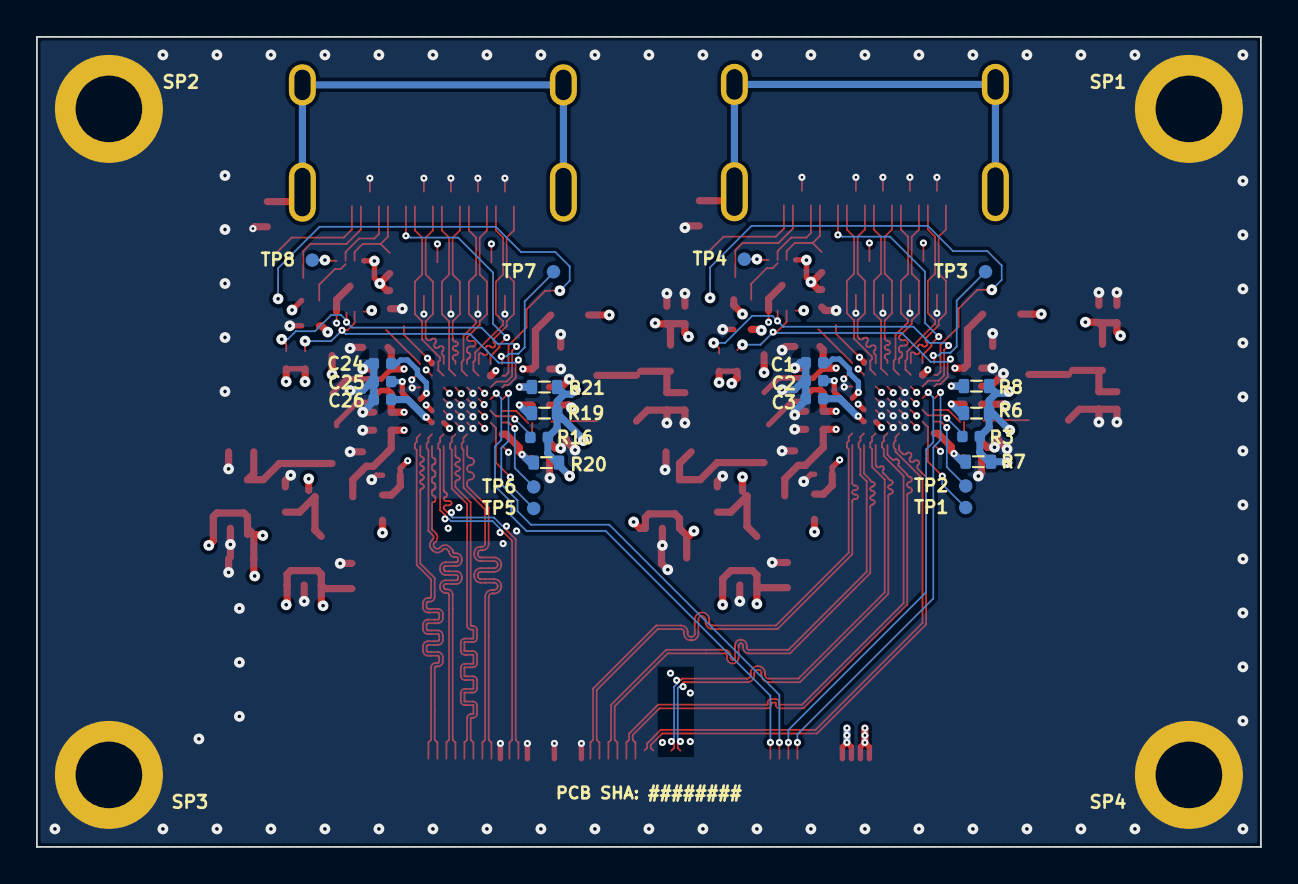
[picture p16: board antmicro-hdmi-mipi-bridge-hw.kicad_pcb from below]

Board: 4 copper layers, 68.0 x 45.0 mm, 121 parts (26 on the bottom side), 107 nets.

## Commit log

2020-12-08 Add design files for release 1.2.1
    [HDMI-MIPI-Bridge.PrjPcb, InputChannel_1.SchDoc, InputChannel_2.SchDoc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]
2020-12-08 Update numbering
    [HDMI-MIPI-Bridge-Rev.1.2.1-bom.csv, HDMI-MIPI-Bridge-Rev.1.2.1.stl, InputChannel_1.SchDoc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]
2020-12-08 Update schematics
2023-11-06 Update schematic PDF
2023-11-06 Rearrange file structure
    [HDMI-MIPI-Bridge-Rev.1.2.1-bom.csv, HDMI-MIPI-Bridge.PrjPcb, InputChannel_1.SchDoc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]
2023-11-06 Ported schematics from altium
    [antmicro-hdmi-mipi-bridge-hw.kicad_pcb, antmicro-hdmi-mipi-bridge-hw.kicad_sch, channel1.kicad_sch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]
2023-11-06 Change components to antmicro library ones
    [68715014522.stp, CON-Molex-505110-1992.stp, Molex_HDMI_471511001.stp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]
2023-11-06 Small fixes to decoupling
    [antmicro-hdmi-mipi-bridge-hw.kicad_sch]
2023-11-06 Layout of the PCB
    [antmicro-hdmi-mipi-bridge-hw.kicad_pcb, antmicro-hdmi-mipi-bridge-hw.kicad_sch, channel1.kicad_sch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]
2023-11-06 Removed old altium files
    [68715014522.stp, CON-Molex-505110-1992.stp, HDMI-MIPI-Bridge.PrjPcb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]
2023-11-06 Added logos
    [antmicro-hdmi-mipi-bridge-hw.kicad_pcb, antmicro-hdmi-mipi-bridge-hw.kicad_sch, channel1.kicad_sch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]
2023-11-06 Revision bump to 1.3.0
    [antmicro-hdmi-mipi-bridge-hw.kicad_pcb, antmicro-hdmi-mipi-bridge-hw.kicad_sch, channel1.kicad_sch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]
2023-11-06 Schematic cleanup
    [channel1.kicad_sch, channel2.kicad_sch, csi.kicad_sch]
2023-11-06 Fixed PCB logos
    [antmicro-hdmi-mipi-bridge-hw.kicad_pcb]
2023-11-06 Added PCB SHA
    [antmicro-hdmi-mipi-bridge-hw.kicad_pcb]
2023-11-06 Updated components
    [antmicro-hdmi-mipi-bridge-hw.kicad_pcb, antmicro-hdmi-mipi-bridge-hw.kicad_sch, csi.kicad_sch]
2023-11-06 Changed mounting holes to stubs
    [antmicro-hdmi-mipi-bridge-hw.kicad_pcb, antmicro-hdmi-mipi-bridge-hw.kicad_sch, csi.kicad_sch]
2023-11-06 Update PCB marking strings
    [HDMI-MIPI-Bridge-Rev.1.2.1-bom.csv, antmicro-hdmi-mipi-bridge-hw.kicad_pcb]
2023-11-06 Update local library of components
    [antmicro-hdmi-mipi-bridge-hw.kicad_pcb, antmicro-hdmi-mipi-bridge-hw.kicad_sch, channel1.kicad_sch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]
2023-11-06 Introduce component standardization
    [antmicro-hdmi-mipi-bridge-hw.kicad_sch, channel1.kicad_sch, channel2.kicad_sch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]
2023-11-07 Add OHP assets
    [stackup.csv]
2024-04-19 [#58304] Migrate project to KiCad7
    [antmicro-hdmi-mipi-bridge-hw.kicad_sch, channel1.kicad_sch, channel2.kicad_sch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]
2024-04-19 [#58304] Perform globlib
    [antmicro-hdmi-mipi-bridge-hw.kicad_sch, channel1.kicad_sch, channel2.kicad_sch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]
2024-04-19 [#58304] Update symbols to global libs
    [antmicro-hdmi-mipi-bridge-hw.kicad_sch, channel1.kicad_sch, channel2.kicad_sch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]
2024-04-19 [#58304] WiP: Update footprints to global libs
    [channel1.kicad_sch, channel2.kicad_sch]
2024-04-24 [#58304] Change J6 to Conn_FFC_WE_68715014x22_CUSTOM_FLIPPED
    [csi.kicad_sch]
2024-04-24 [#58304] Bump revision to 1.3.2
    [antmicro-hdmi-mipi-bridge-hw.kicad_sch]
2024-04-25 [#58304] Revert flipping J6
    [csi.kicad_sch]
2024-05-08 [#58304] Update ICs fileds visibility
    [channel1.kicad_sch, channel2.kicad_sch, csi.kicad_sch]
2024-05-08 [#58304] Update PCA9517ATP symbol
    [channel1.kicad_sch, channel2.kicad_sch]
2024-05-08 [#58304] kmake dnp
    [antmicro-hdmi-mipi-bridge-hw.kicad_sch, channel1.kicad_sch, channel2.kicad_sch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]
2024-05-08 [#58304] Fix power flags orientation
    [channel1.kicad_sch, channel2.kicad_sch, csi.kicad_sch]
2024-05-08 [#58304] Fix ERC
    [antmicro-hdmi-mipi-bridge-hw.kicad_sch, channel1.kicad_sch, channel2.kicad_sch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]
2024-05-08 [#58304] Fix DRC
    [antmicro-hdmi-mipi-bridge-hw.kicad_sch]
2024-05-08 [#58304] Regenerate OHP assets
    [antmicro-hdmi-mipi-bridge-hw-BOM-populated.csv]
2024-06-05 [#58304] Allign power symbol labels
    [channel1.kicad_sch, channel2.kicad_sch, csi.kicad_sch]
2024-06-05 [#58304] Update spacers footprint
2024-06-05 [#58304] Fix schematic after components lib rebase
    [antmicro-hdmi-mipi-bridge-hw.kicad_sch, channel1.kicad_sch, channel2.kicad_sch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]
2024-06-05 [#58304] Update OHP assets
    [antmicro-hdmi-mipi-bridge-hw-BOM-populated.csv]
2024-06-07 [#58304] Update MP from the library
    [channel1.kicad_sch]
